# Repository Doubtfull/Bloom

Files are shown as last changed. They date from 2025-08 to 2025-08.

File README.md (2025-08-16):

# BLOOM

BLOOM is the first keyboard I designed and built. It’s an 80% mechanical keyboard with 87 keys, giving a good balance between compact size and full functionality. I used a Raspberry Pi Pico as the microcontroller, and wired everything by hand based on a custom schematic.

The case is made to be simple and functional. I chose a gradient keycap set to add some colour variation. Once fully built, the colours move gradually across the board from one shade to another. The firmware supports basic typing functions, and I included a rotary encoder for volume control. An LED turns on when the board is powered.

This project helped me learn how to design circuits and write firmware. It’s fully custom and made from the ground up.

## Why?
I decided to build this keyboard because I’ve always been interested in mechanical keyboards, but never had one of my own. I wanted something that felt personal and something I could use every day. I’ve always liked the look of gradient keycaps, and choosing the colours gave me a way to make the board feel more like mine. Since I plan to use this keyboard 24/7, building it gave me the motivation to get everything right and make it exactly how I want.

| Item | Amount | Price CAD [$] | Link |
|:---:|---|---|---|
| Cherry MX Switches | 87 | 35.38 | https://www.aliexpress.com/item/1005006255961111.html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"order"%3A"1044"%2C"eval"%3A"1"%7D&pdp_npi=4%40dis%21CAD%218.99%211.39%21%21%2145.94%217.11%21%402101d9ee17529990794214549e88c5%2112000036489552472%21sea%21CA%210%21ABX&curPageLogUid=JNMqebzd3gPt&utparam-url=scene%3Asearch%7Cquery_from%3A |
| Keycaps | 87 | Free (I'll pay for it) | https://drop.com/buy/artifact-bloom-series-keycap-set-dusk |
| Stabilizers | 5 | 19.74 | https://www.amazon.ca/DUROCK-Stabilizer-Innovative-Pre-Clipped-Stabilizers/dp/B0CTHT34MJ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 |
| LED_SK6812MINI | 1 | Free | |
| Diode_DO-35 | 87 | 10.68 | https://www.amazon.ca/Projects-1N914-Diode-General-Purpose/dp/B08MDHZ7ZL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 | 
| RotaryEncoder_Alps_EC11E-Switch_Vertical_H20mm| 1 | Free | |
| Raspberry Pi Pico | 1 | 15.95 | https://www.amazon.ca/Official-Raspberry-Pi-Pico-Dual-core/dp/B0B5H2LNL2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 |
| M3x16mm screws | 4 | 13.01 | https://www.amazon.ca/M3x16mm-Button-Socket-Screws-stainless/dp/B075PQLF83?gQT=1&th=1 |
| 4x M3x5mx4mm heatset inserts  | 4 | 11.08 |  https://www.aliexpress.com/item/4000232858343.html?gatewayAdapt=usa2glo4itemAdapt |
| PCB | 1 | 33.80 | https://jlcpcb.com |
| Total | | 157.36 (with tax)| |

Total Price USD = $113.87

## Schematic
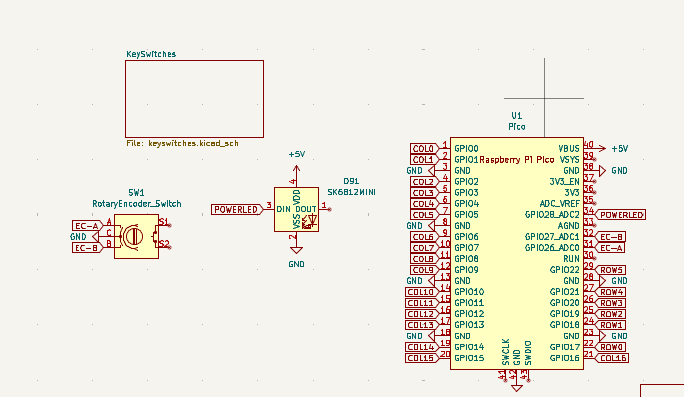
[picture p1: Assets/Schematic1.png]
schematic

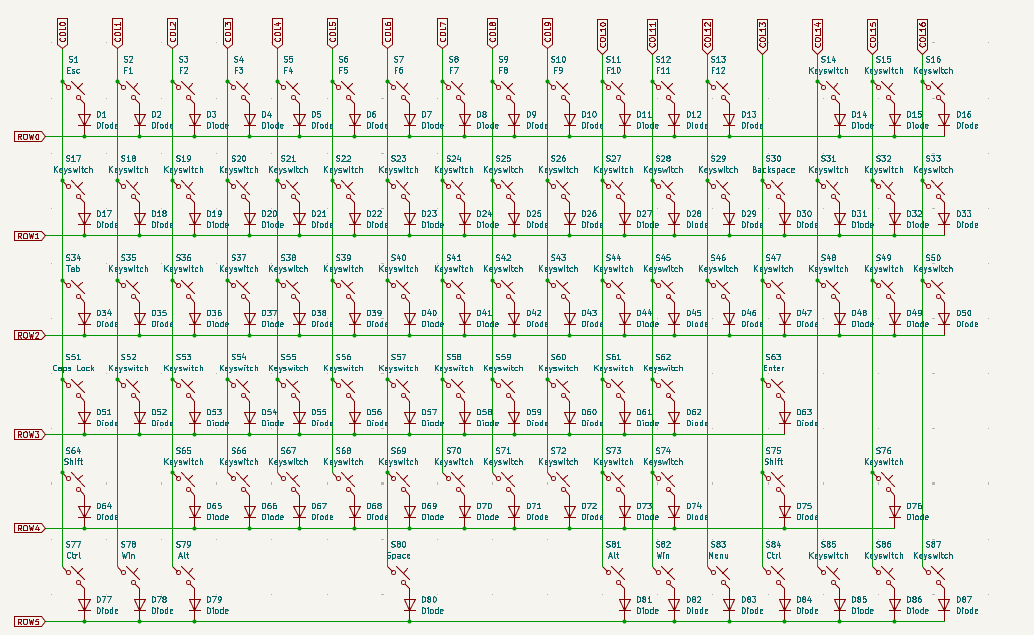
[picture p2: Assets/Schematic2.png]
schematic


## PCB
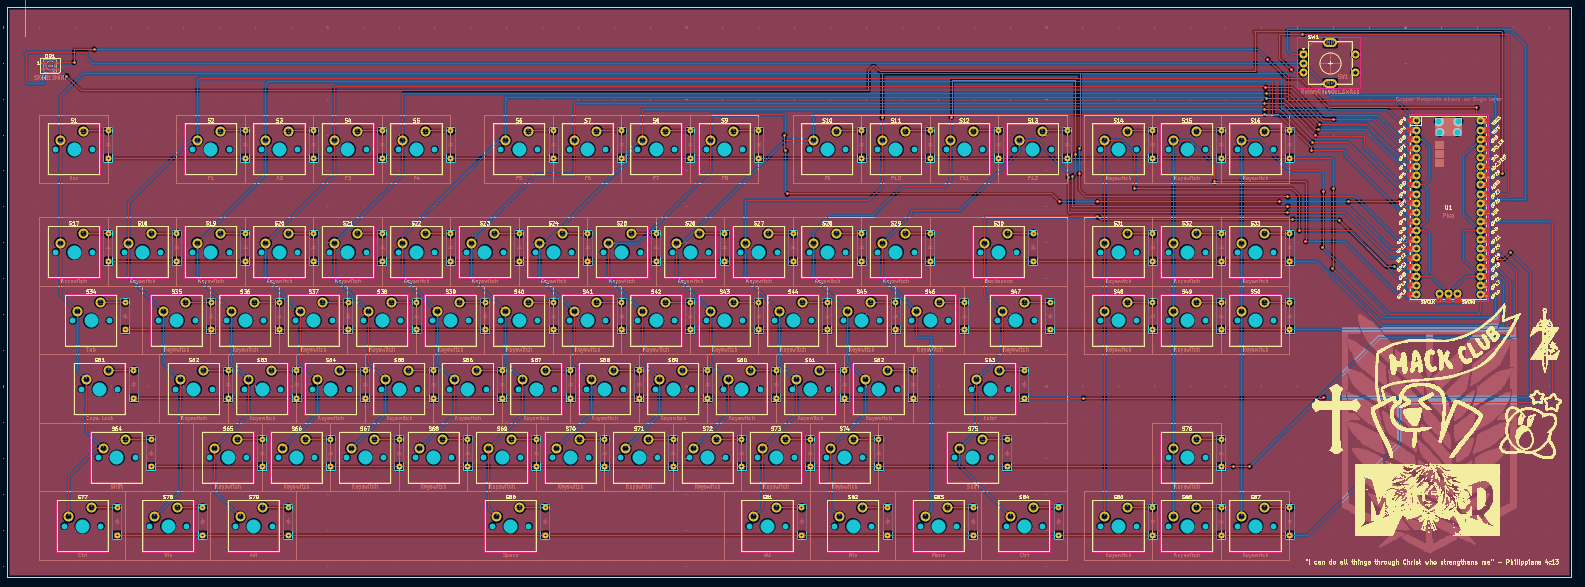
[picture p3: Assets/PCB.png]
PCB


## PCB Render
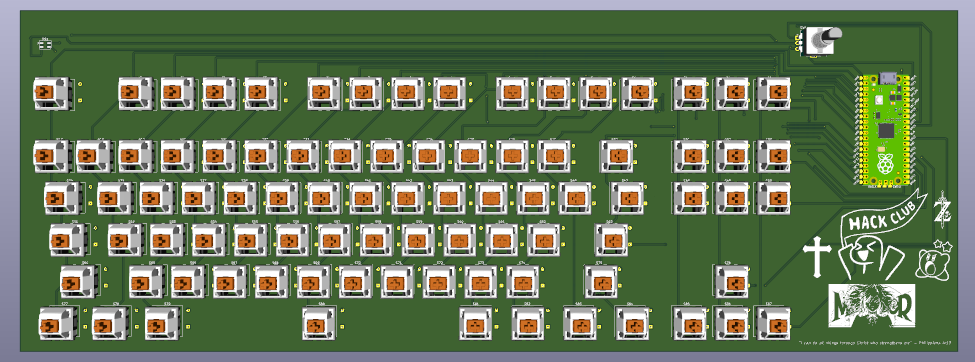
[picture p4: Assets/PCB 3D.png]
PCB Render


## CAD Base
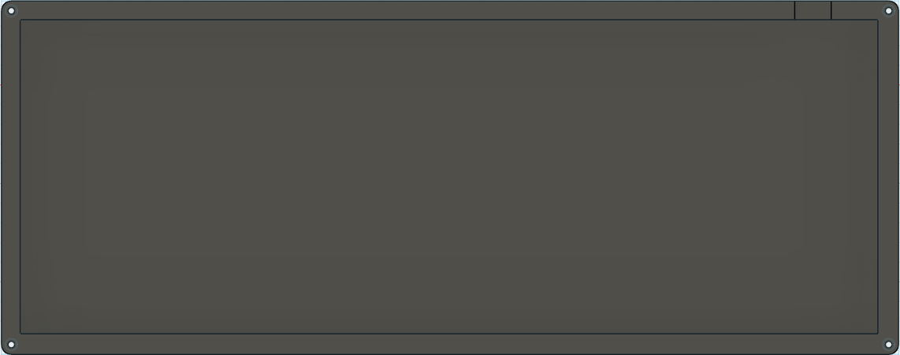
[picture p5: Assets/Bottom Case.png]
CAD Base


## CAD Cover
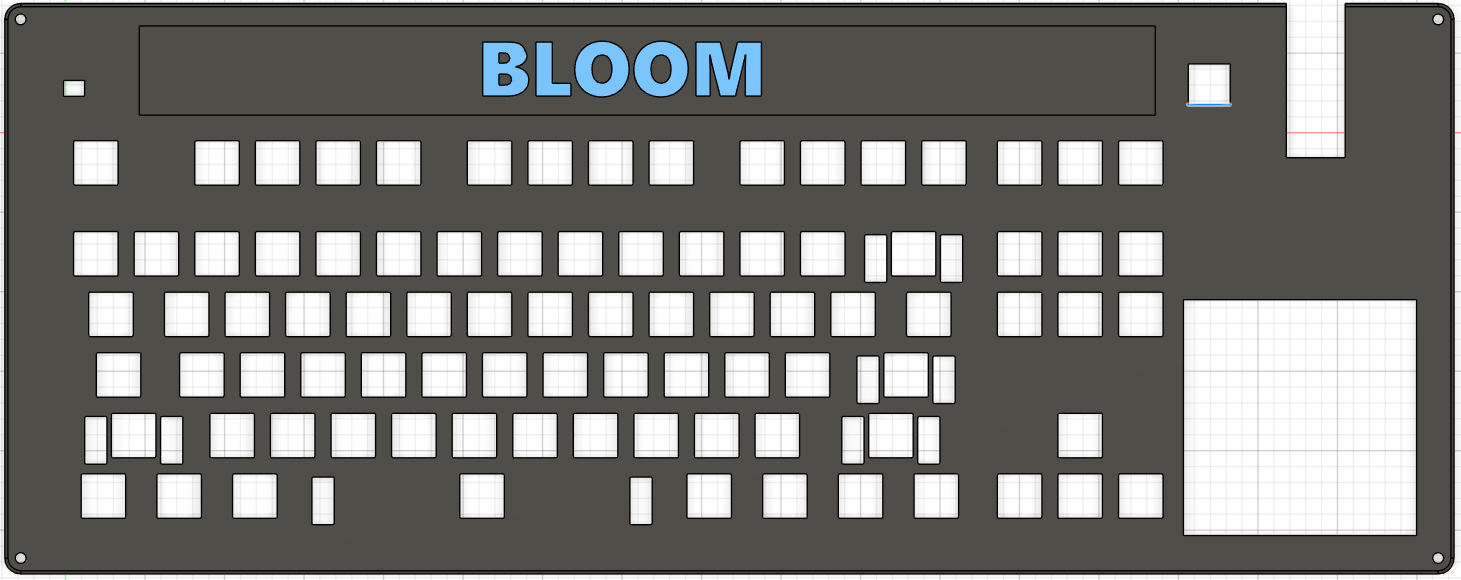
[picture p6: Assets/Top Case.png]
CAD Cover


## Case Compatibility
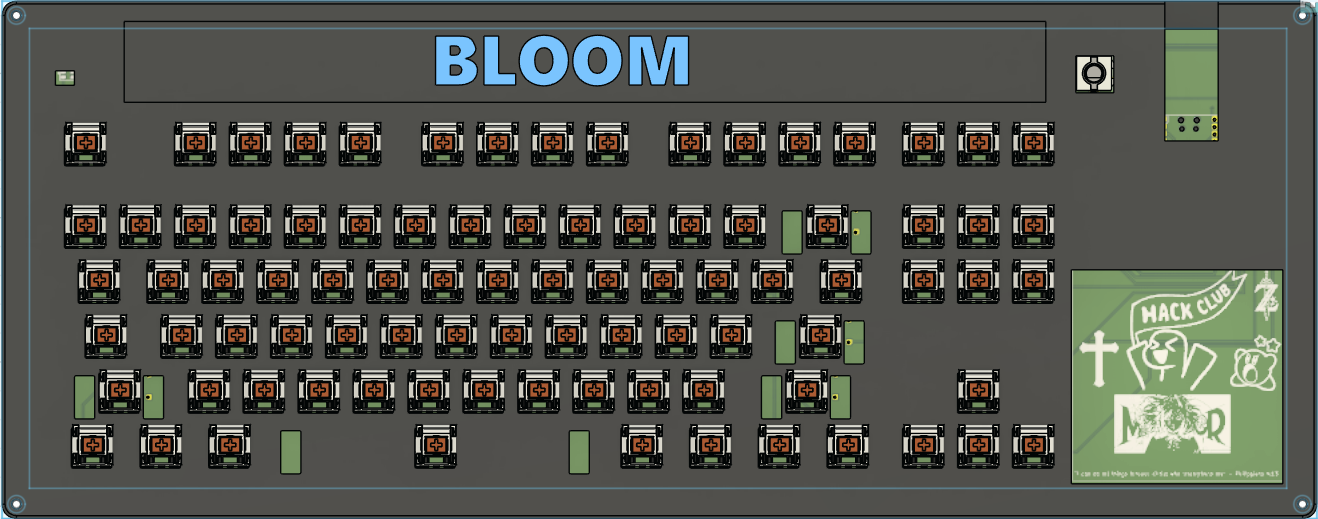
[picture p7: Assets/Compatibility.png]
case compatibility

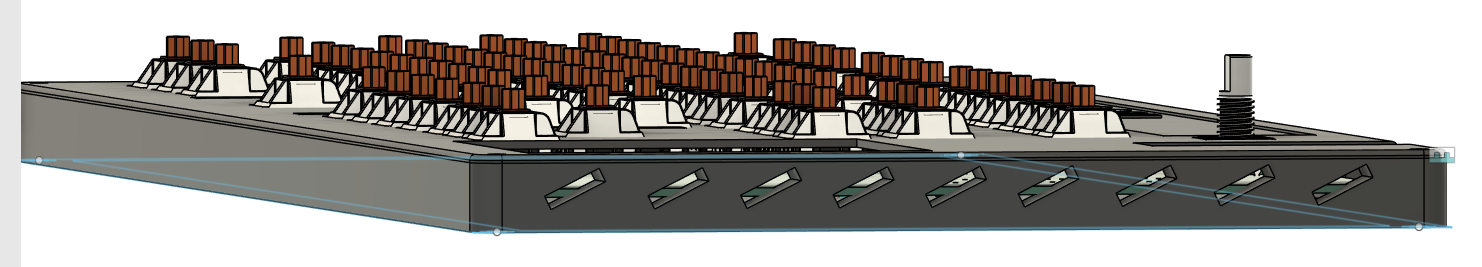
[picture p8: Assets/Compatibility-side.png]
case compatibility


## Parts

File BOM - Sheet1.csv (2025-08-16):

Item | Price (CAD) | Link
87x Cherry MX Switches | $35.38 | https://www.aliexpress.com/item/1005006255961111.html?pdp_ext_f=%7B"order"%3A"1044"%2C"eval"%3A"1"%7D&pdp_npi=4%40dis%21CAD%218.99%211.39%21%21%2145.94%217.11%21%402101d9ee17529990794214549e88c5%2112000036489552472%21sea%21CA%210%21ABX&curPageLogUid=JNMqebzd3gPt&utparam-url=scene%3Asearch%7Cquery_from%3A
87x Keycaps | Free | https://drop.com/buy/artifact-bloom-series-keycap-set-dusk
1x LED_SK6812MINI | Free
5x Stabilizers | $19.74 | https://www.amazon.ca/DUROCK-Stabilizer-Innovative-Pre-Clipped-Stabilizers/dp/B0CTHT34MJ
1x RotaryEncoder_Alps_EC11E-Switch_Vertical_H20mm | Free
4x M3x16mm screws | $13.01 | https://www.amazon.ca/M3x16mm-Button-Socket-Screws-stainless/dp/B075PQLF83?gQT=1&th=1
4x M3x5mx4mm heatset inserts | $11.08 | https://www.aliexpress.com/item/4000232858343.html?gatewayAdapt=usa2glo4itemAdapt
1x Raspberry Pi Pico | $15.95 | https://www.amazon.ca/Official-Raspberry-Pi-Pico-Dual-core/dp/B0B5H2LNL2
87x Diodes | $10.68 | https://www.amazon.ca/Projects-1N914-Diode-General-Purpose/dp/B08MDHZ7ZL
PCB | $33.80 | https://jlcpcb.com
Total | $157.36 (with tax)

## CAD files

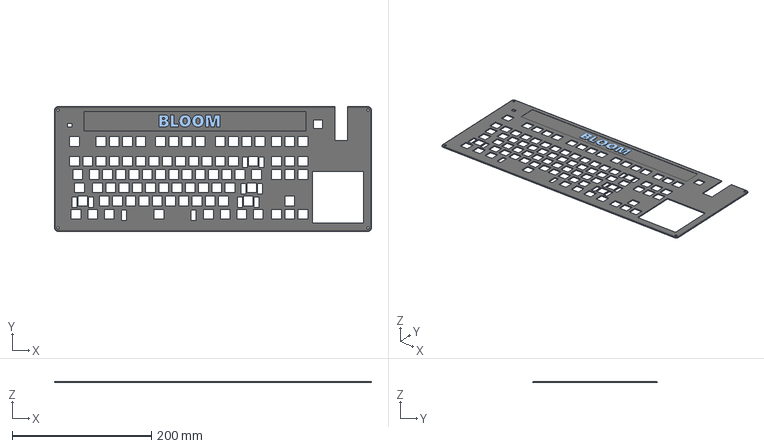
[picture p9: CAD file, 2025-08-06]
CAD/KeebTopside.step
455.8 x 179.4 x 1.50 mm

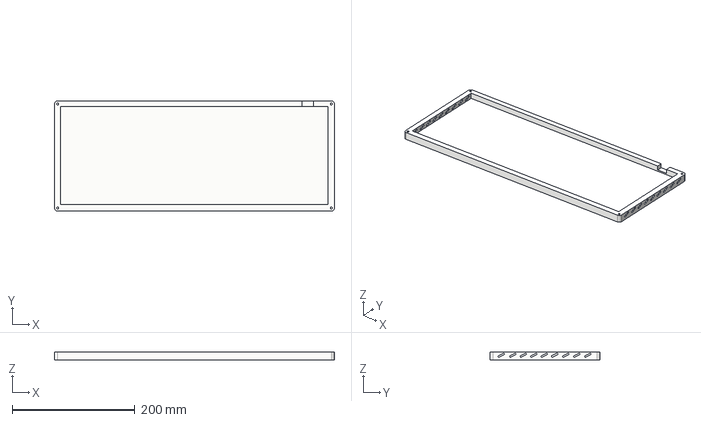
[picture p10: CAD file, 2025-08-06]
CAD/KeebBottomv1.step
455.8 x 179.4 x 13.0 mm

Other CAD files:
Production/KeebTopside.step
Production/KeebBottomv1.step

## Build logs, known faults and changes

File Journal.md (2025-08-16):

---
title: BLOOM
author: Ayomide Abraham
description: 80% Mechanical Keyboard
created at: 07/20/2025
total time: 13 hours
---

Time: 5 hours

- I started by brainstorming what I wanted on my keyboard. I looked at layouts, features, and the number of keys I would need for daily use.
- I researched how to build an 80% keyboard from scratch. This was my first time making a keyboard, so I had to learn each step carefully.
- I began working on the schematic, mapping out how each key would connect to the microcontroller and how the rows and columns would be wired.

One of the biggest challenges was choosing the right microcontroller. Many options were either too expensive or didn’t have enough GPIO pins. After some research, I found the Raspberry Pi Pico. It was affordable, reliable, and had more than enough I/O for the 87-key layout. Once I chose the Pico, building the schematic became much more easier.

schematic
schematic

Day 2

time: 8 hours

- Started routing the PCB

Routing the PCB was fairly easy and after I finished, I got 0 errors from DRC first try! I also changed the PCB design a little by adding field zones. It makes the PCB looks so much better!

It wasn't until I finished wiring till I realized that my pico was too low. But instead I'll just make a longer hole so that the cable can reach the pico.

PCB
PCB Render

- Then I got on Fusion and I started to work on the case
- I created the bottom and top case fairly quickly
- I then made a little opening to show off the silkscreen

The case that I made is very similar to the hackpad case that I made, this time I wanted to show off some of the PCB design.

CAD Base
CAD Cover
case compatibility

Don't worry there's more than enough space for the cable to connect to the pico!

I also worked and finished my BOM, compiled and sorted all my file for submission.

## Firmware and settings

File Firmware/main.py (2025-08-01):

import board
import digitalio
from kmk.kmk_keyboard import KMKKeyboard
from kmk.scanners import MatrixScanner
from kmk.keys import KC
from kmk.extensions.encoder import EncoderHandler

keyboard = KMKKeyboard()

keyboard.row_pins = [
    board.GP26, board.GP27, board.GP28, board.GP22, board.GP21, board.GP20
]

keyboard.col_pins = [
    board.GP0, board.GP1, board.GP2, board.GP3, board.GP4, board.GP5, board.GP6, board.GP7,
    board.GP8, board.GP9, board.GP10, board.GP11, board.GP12, board.GP13, board.GP14, board.GP15
]

keyboard.diode_orientation = MatrixScanner.DIODE_COL2ROW

keyboard.keymap = [
    [
        KC.ESC, KC.F1, KC.F2, KC.F3, KC.F4, KC.F5, KC.F6, KC.F7, KC.F8, KC.F9, KC.F10, KC.F11, KC.F12, KC.NO, KC.NO, KC.NO,
        KC.TAB, KC.Q, KC.W, KC.E, KC.R, KC.T, KC.Y, KC.U, KC.I, KC.O, KC.P, KC.BSPC,
        KC.CAPS, KC.A, KC.S, KC.D, KC.F, KC.G, KC.H, KC.J, KC.K, KC.L, KC.ENT,
        KC.LSFT, KC.Z, KC.X, KC.C, KC.V, KC.B, KC.N, KC.M, KC.COMM, KC.DOT, KC.RSFT,
        KC.LCTL, KC.LGUI, KC.LALT, KC.SPC, KC.RALT, KC.APP, KC.RCTL
    ]
]

# Rotary Encoder setup (EC_A=GP27, EC_B=GP26)
encoder_handler = EncoderHandler()
encoder_handler.pins = ((board.GP27, board.GP26),)
encoder_handler.map = (((KC.VOLD, KC.VOLU),),)
keyboard.extensions.append(encoder_handler)

if __name__ == '__main__':
    keyboard.go()

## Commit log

2025-08-01 Most of the required files
    [Keeb.kicad_sch, KeebBottomv1.step, KeebTopside.step]
2025-08-01 Added the pictures
    [KeebBottomv1.step, KeebTopside.step]
2025-08-01 Updated journal, readme and added BOM.csv
    [BOM - Sheet1.csv]
2025-08-06 Made the case more complicated for resubmition
    [KeebBottomv1.step, KeebTopside.step]
2025-08-16 Update BOM - Sheet1.csv
    [BOM - Sheet1.csv]
